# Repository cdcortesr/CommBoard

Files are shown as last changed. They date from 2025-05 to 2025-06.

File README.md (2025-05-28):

## Communication Board (CommBoard)
<picture>
  <source media="(prefers-color-scheme: dark)" srcset="https://i.imgur.com/UVEQvyd.jpeg">
  <source media="(prefers-color-scheme: light)" srcset="https://i.imgur.com/UVEQvyd.jpeg">
  a.
</picture>

Self-built serial communication board based on an STM32 microcontroller, designed for embedded systems applications. Key features and technical details include:

• Communication Interfaces:

&nbsp;&nbsp;&nbsp;&nbsp;• I²C (Inter-Integrated Circuit) interface for peripheral connectivity.

&nbsp;&nbsp;&nbsp;&nbsp;• UART (Universal Asynchronous Receiver-Transmitter) for serial communication.

&nbsp;&nbsp;&nbsp;&nbsp;• JTAG interface for in-circuit programming and debugging.

&nbsp;&nbsp;&nbsp;&nbsp;• USB for data transfer and power input.

• PCB Design and Manufacturing:

&nbsp;&nbsp;&nbsp;&nbsp;• Dual-layer printed circuit board (PCB) designed using KiCad.

&nbsp;&nbsp;&nbsp;&nbsp;• Fabricated by JLCPCB (PCB manufacturer).

&nbsp;&nbsp;&nbsp;&nbsp;• Self-assembled using a combination of reflow oven soldering and manual hand soldering techniques.

• Power Supply:

&nbsp;&nbsp;&nbsp;&nbsp;• Powered via USB connection.

&nbsp;&nbsp;&nbsp;&nbsp;• Integrated Low Dropout Regulator (LDO) for stable voltage supply.

This project demonstrates proficiency in hardware design, embedded programming, and hands-on electronics assembly.

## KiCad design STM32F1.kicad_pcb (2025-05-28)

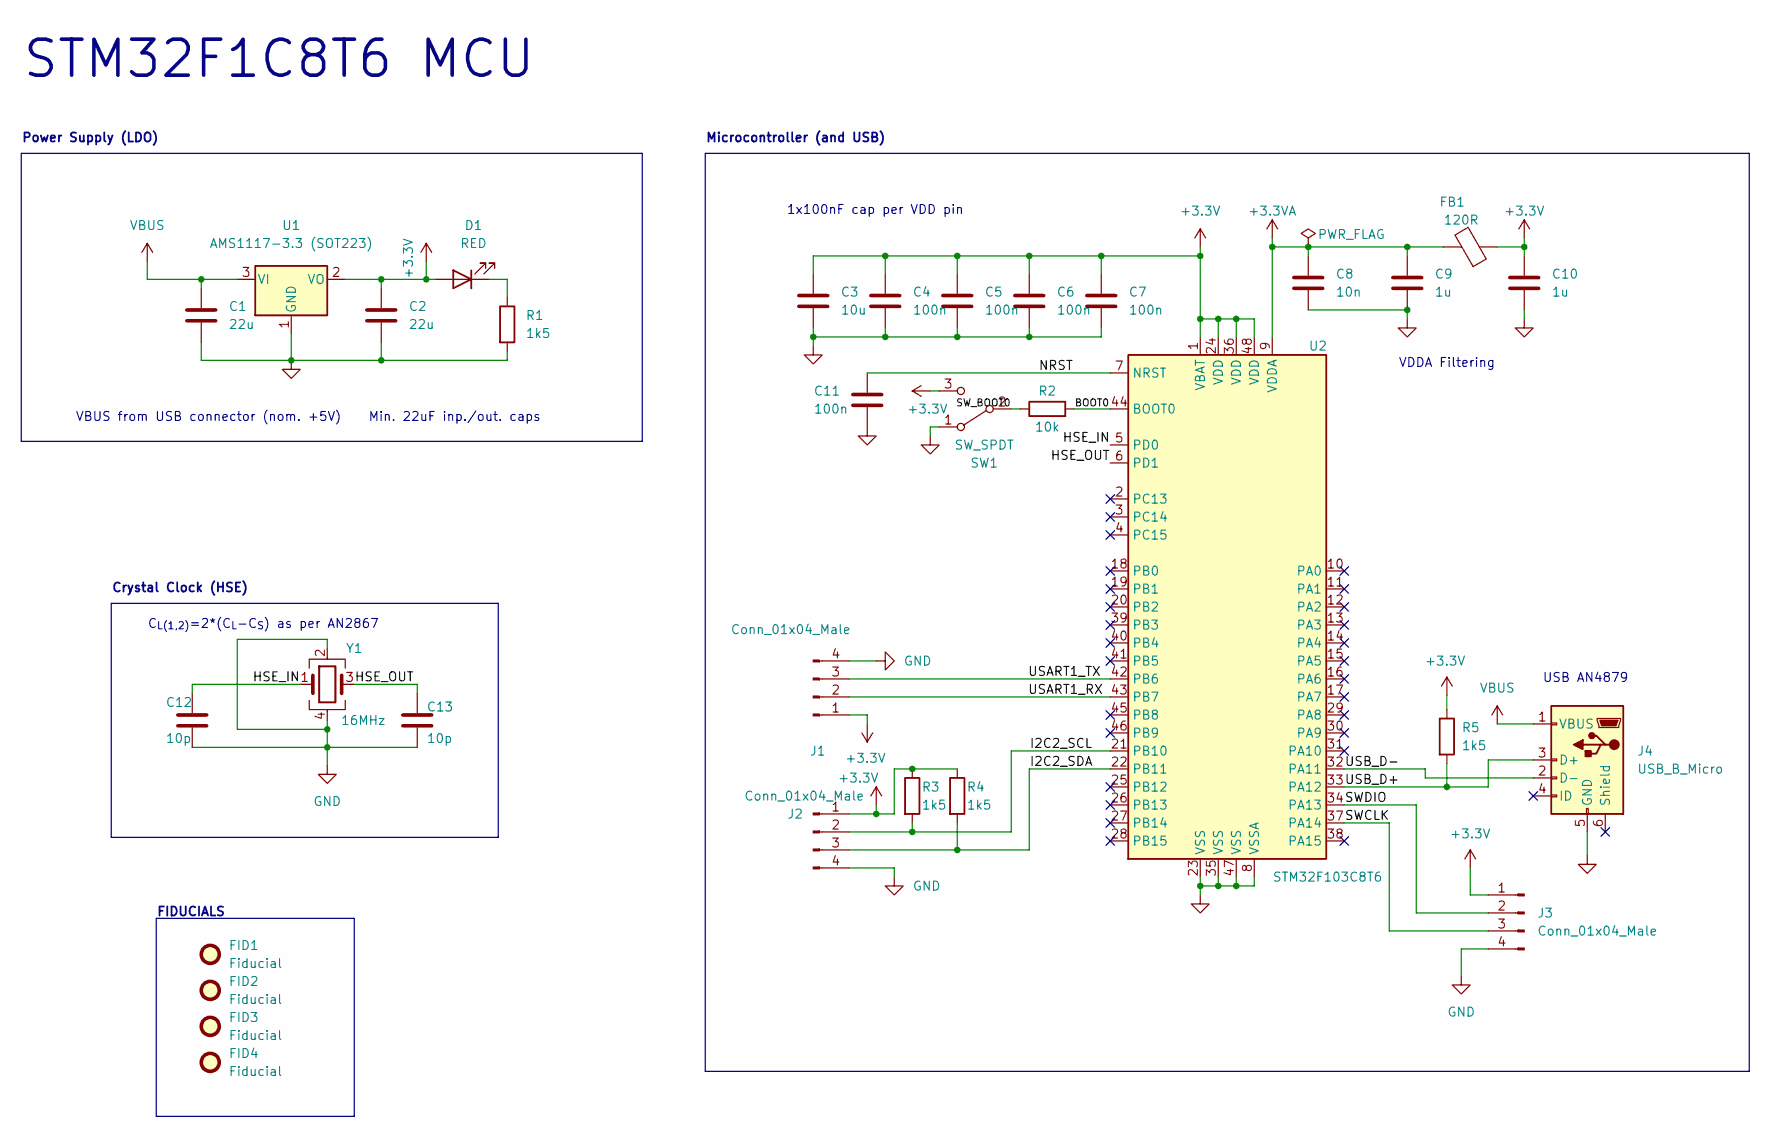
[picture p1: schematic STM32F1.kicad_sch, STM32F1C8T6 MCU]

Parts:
C1, C2: 22u; C_0805_2012Metric
C3: 10u; C_0603_1608Metric
C4, C5, C6, C7, C11: 100n; C_0402_1005Metric
C8: 10n; C_0603_1608Metric
C9, C10: 1u; C_0402_1005Metric
C12, C13: 10p; C_0402_1005Metric
D1: RED; LED_0603_1608Metric
FB1: 120R; L_0201_0603Metric
FID1, FID2, FID3, FID4: Fiducial; Fiducial_1mm_Mask2mm
J1, J2, J3: Conn_01x04_Male; PinHeader_1x04_P2.54mm_Vertical
J4: USB_B_Micro; USB_Micro-B_Wuerth_629105150521
R1, R3, R4, R5: 1k5; R_0402_1005Metric
R2: 10k; R_0402_1005Metric
SW1: SW_SPDT; SW_JS102011SAQN
U1: AMS1117-3.3 (SOT223); SOT-223-3_TabPin2
U2: STM32F103C8T6; LQFP-48_7x7mm_P0.5mm
Y1: 16MHz; Crystal_SMD_3225-4Pin_3.2x2.5mm

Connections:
+3.3VA: C8.1, C9.1, FB1.2, U2.9 (VDDA)
+3V3: C2.1, C3.1, C4.1, C5.1, C6.1, C7.1, C10.1, D1.2 (A), FB1.1, J1.1, J2.1, J3.1, R3.1, R4.1, R5.1, SW1.3 (C), U1.2 (VO), U2.1 (VBAT), U2.24 (VDD), U2.36 (VDD), U2.48 (VDD)
/BOOT0: R2.2, U2.44 (BOOT0)
/HSE_IN: C12.1, U2.5 (PD0), Y1.1
/HSE_OUT: C13.1, U2.6 (PD1), Y1.3
/I2C2_SCL: J2.2, R3.2, U2.21 (PB10)
/I2C2_SDA: J2.3, R4.2, U2.22 (PB11)
/NRST: C11.1, U2.7 (NRST)
/SWCLK: J3.3, U2.37 (PA14)
/SWDIO: J3.2, U2.34 (PA13)
/SW_BOOT0: R2.1, SW1.2 (B)
/USART1_RX: J1.2, U2.43 (PB7)
/USART1_TX: J1.3, U2.42 (PB6)
/USB_D+: J4.3 (D+), R5.2, U2.33 (PA12)
/USB_D-: J4.2 (D-), U2.32 (PA11)
GND: C1.2, C2.2, C3.2, C4.2, C5.2, C6.2, C7.2, C8.2, C9.2, C10.2, C11.2, C12.2, C13.2, J1.4, J2.4, J3.4, J4.5 (GND), R1.2, SW1.1 (A), U1.1 (GND), U2.8 (VSSA), U2.23 (VSS), U2.35 (VSS), U2.47 (VSS), Y1.2, Y1.4
unnamed: D1.1 (K), R1.1
VBUS: C1.1, J4.1 (VBUS), U1.3 (VI)

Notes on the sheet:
1x100nF cap per VDD pin
Power Supply (LDO)
${TITLE}
VDDA Filtering
Crystal Clock (HSE)
FIDUCIALS
Microcontroller (and USB)
VBUS from USB connector (nom. +5V) Min. 22uF inp./out. caps
C_{L(1,2)}=2*(C_{L}-C_{S}) as per AN2867
USB AN4879

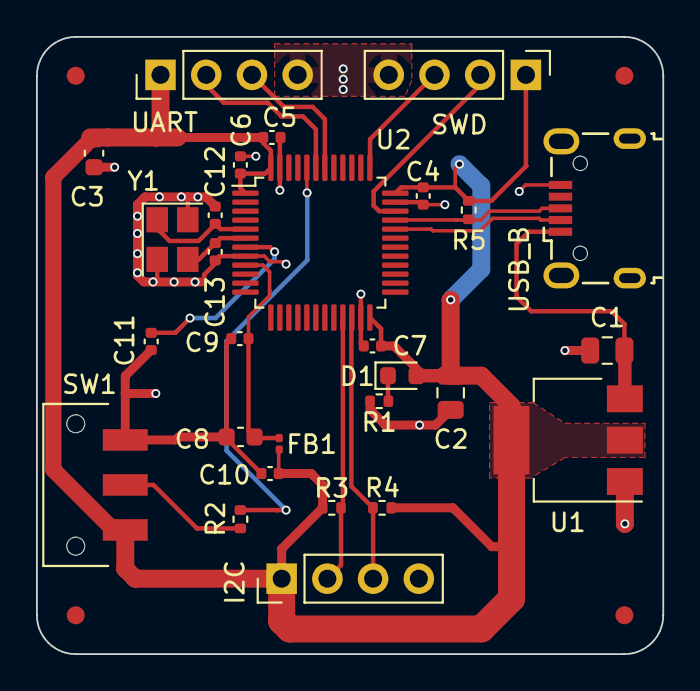
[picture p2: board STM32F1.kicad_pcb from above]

Board: 2 copper layers, 34.8 x 34.3 mm, 32 parts (0 on the bottom side), 18 nets.

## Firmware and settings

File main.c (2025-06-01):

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
/* Includes ------------------------------------------------------------------*/
#include "main.h"

I2C_HandleTypeDef hi2c2;

UART_HandleTypeDef huart1;

/* USER CODE BEGIN PV */
uint8_t data_tx []="A";
uint16_t address=0x00;
/* USER CODE END PV */

void SystemClock_Config(void);
static void MX_GPIO_Init(void);
static void MX_USART1_UART_Init(void);
static void MX_I2C2_Init(void);
/* USER CODE BEGIN PFP */
#define PUTCHAR_PROTOTYPE int __io_putchar(int ch)
/* USER CODE END PFP */

/**
  * @brief  The application entry point.
  * @retval int
  */
int main(void)
{
  /* MCU Configuration--------------------------------------------------------*/

  /* Reset of all peripherals, Initializes the Flash interface and the Systick. */
  HAL_Init();

  /* Configure the system clock */
  SystemClock_Config();

  /* Initialize all configured peripherals */
  MX_GPIO_Init();
  MX_USART1_UART_Init();
  MX_I2C2_Init();
  /* USER CODE BEGIN 2 */
  int j=0;
  /* USER CODE END 2 */

  /* Infinite loop */
  /* USER CODE BEGIN WHILE */

  while (1)
  {

    /* USER CODE END WHILE */

    /* USER CODE BEGIN 3 */
//	  if(j==100){
//		  j=1;
//	  }
	  printf("hola%d\n\r",j);
	  j++;
	  HAL_Delay(50);
	  for(;address<256;address++){
		  if(HAL_I2C_Master_Transmit(&hi2c2,address,data_tx,0,0xFFF)==HAL_OK){
			  printf("Found Address = 0x%02x\n\r",address);
		  }
	  }

  }
  /* USER CODE END 3 */
}

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
/* USER CODE BEGIN 4 */
PUTCHAR_PROTOTYPE
{
	HAL_UART_Transmit(&huart1, (uint8_t *)&ch, 1, 0xFFFF);
	return ch;
}
/* USER CODE END 4 */
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

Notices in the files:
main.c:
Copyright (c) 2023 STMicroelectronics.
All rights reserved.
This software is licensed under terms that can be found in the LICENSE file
